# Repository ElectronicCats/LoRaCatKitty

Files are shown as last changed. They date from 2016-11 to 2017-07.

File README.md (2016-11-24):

# LoRa Cat: Kitty

Electronic Cats invests time and resources providing this open source design, please support Electronic Cats and open-source hardware by purchasing products from Electronic Cats!

Designed by Electronic Cats.

Firmware released under an GNU AGPL v3.0 license. See the LICENSE file for more information.

Hardware released under an CERN Open Hardware Licence v1.2. See the LICENSE_HARDWARE file for more information.

Electronic Cats is a registered trademark, please do not use if you sell these PCBs.

23 Nov 2016

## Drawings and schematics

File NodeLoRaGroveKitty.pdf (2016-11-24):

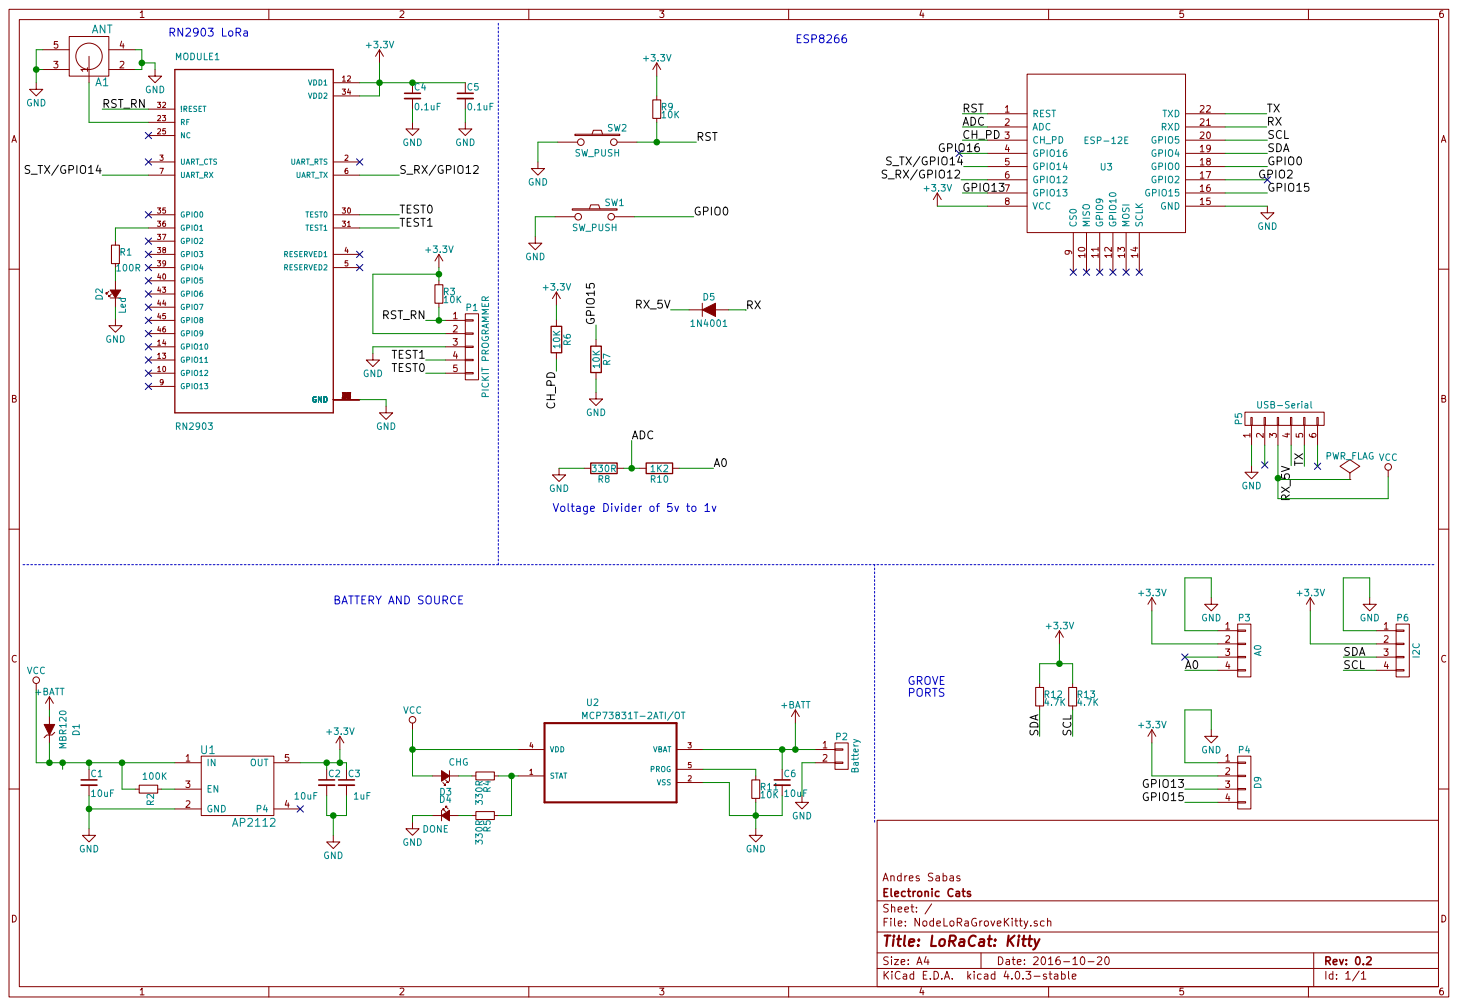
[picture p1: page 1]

9 MISO 10 GPIO5 20 GPIO9 11 RXD 21 GPIO10 12 TXD 22 MOSI 13 SCLK 14 GND 15 GPIO15 16 GPIO2 17 GPIO0 18 GPIO4 19 U3 ESP-12E TXRX

Voltage Divider of 5v to 1v

File: NodeLoRaGroveKitty.sch Sheet: / Electronic Cats Andres Sabas

Id: 1/1 Title: LoRaCat: Kitty

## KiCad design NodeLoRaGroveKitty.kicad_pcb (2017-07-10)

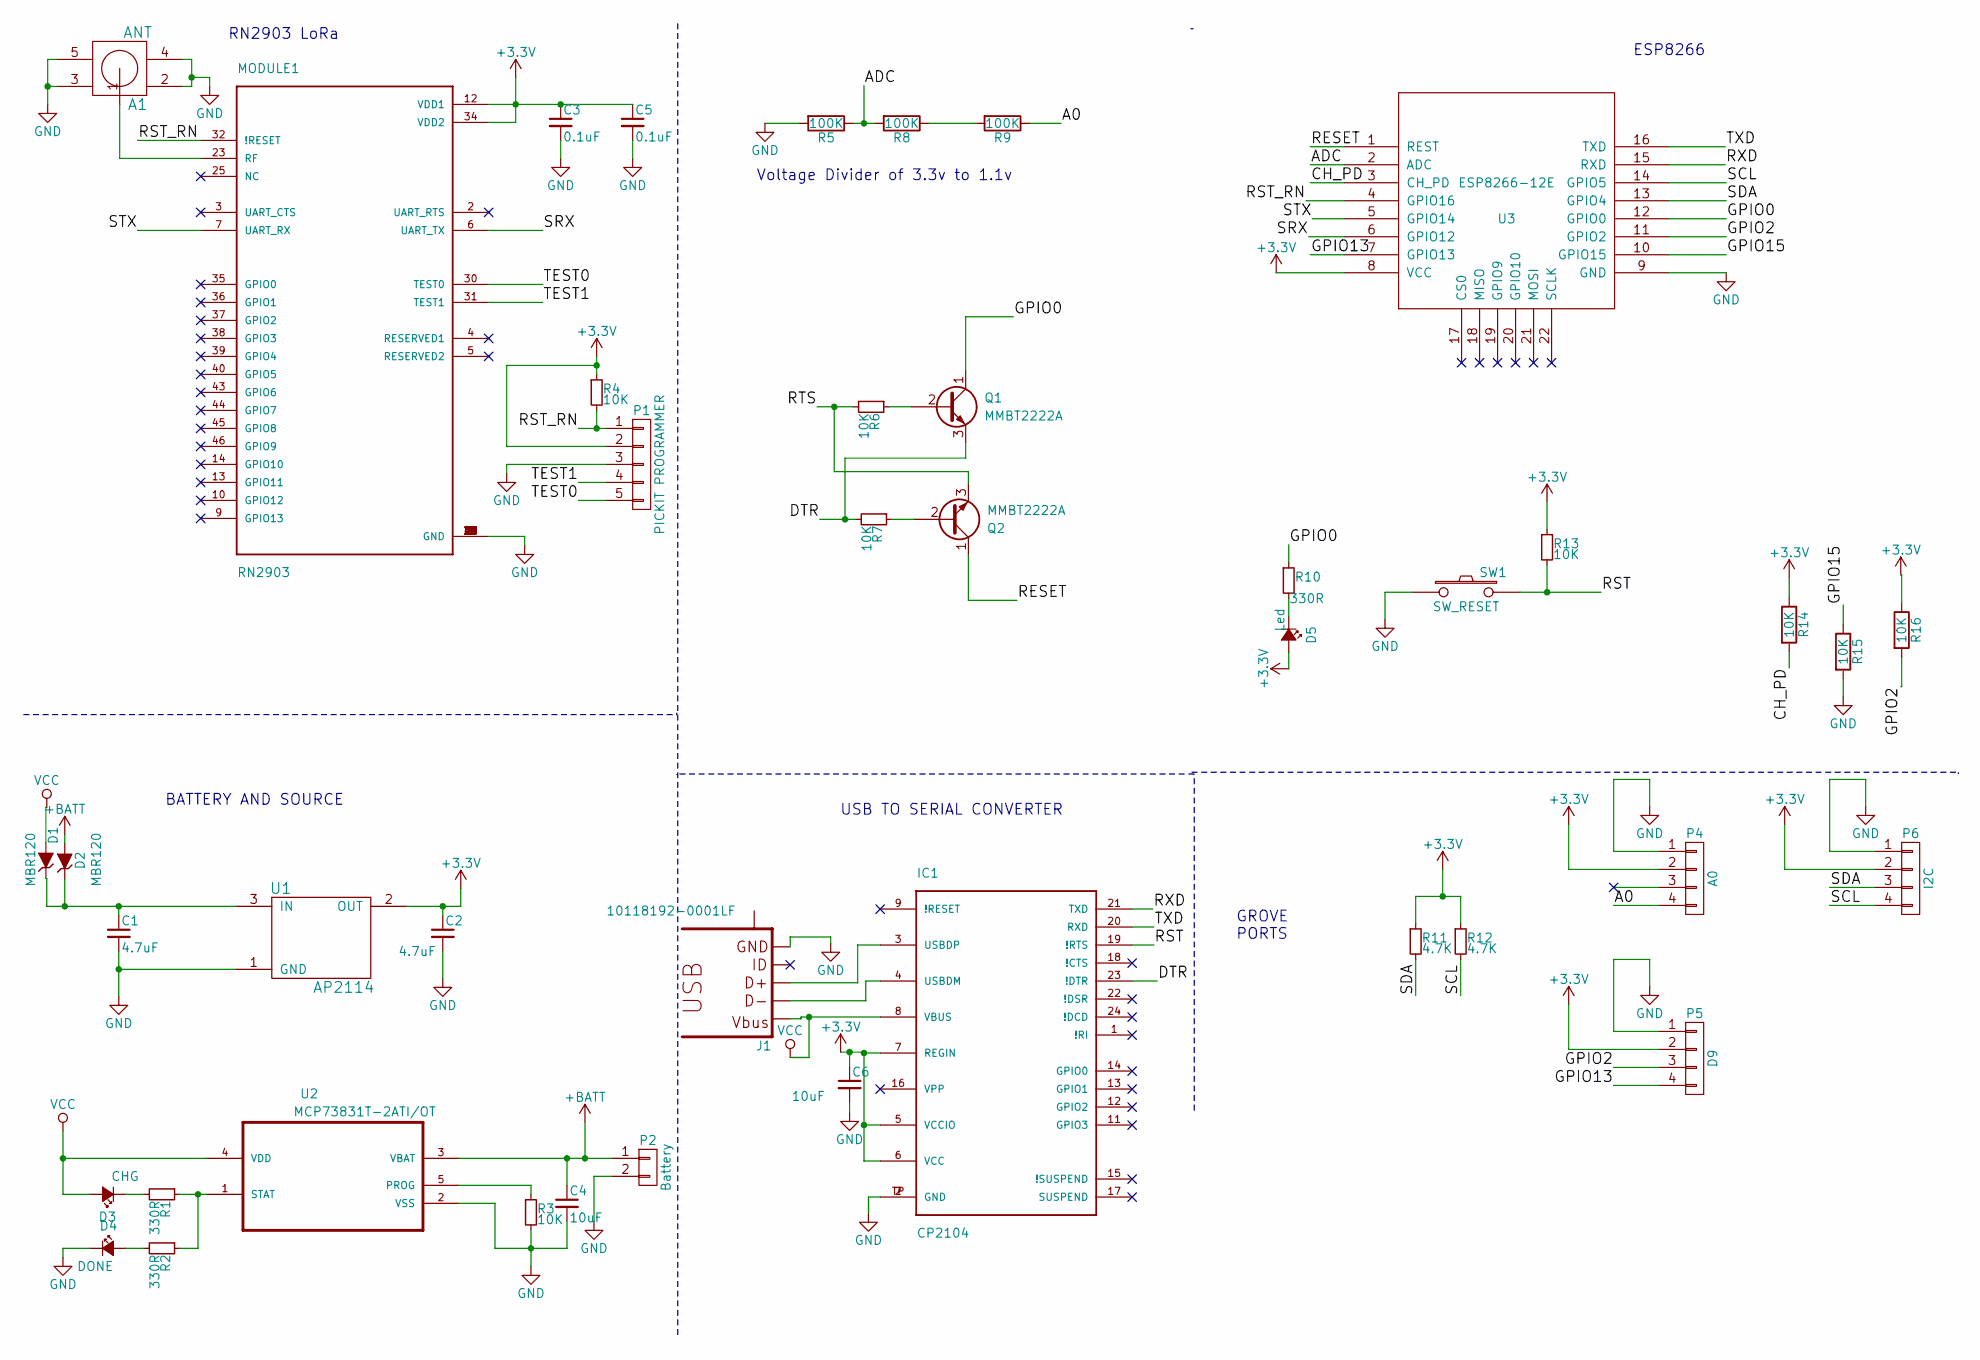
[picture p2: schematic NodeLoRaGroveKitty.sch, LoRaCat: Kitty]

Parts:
A1: ANT; SMA_Conn_Ant
C1, C2: 4.7uF; C_0805_HandSoldering
C3, C5: 0.1uF; C_0805_HandSoldering
C4, C6: 10uF; C_0805_HandSoldering
D1, D2: MBR120; D_SOD-123
D3: CHG; LED_0805
D4: DONE; LED_0805
D5: Led; LED_0805
IC1: CP2104; QFN-24_4x4mm_Pitch0.5mm_NoMask
J1: 10118192-0001LF
MODULE1: RN2903; RN2483
P1: PICKIT PROGRAMMER; Pin_Header_Straight_1x05_Pitch2.54mm
P2: Battery; panelmate_smd_2
P4: A0; JST_PH_S4B-PH-SM4-TB_04x2.00mm_Angled
P5: D9; JST_PH_S4B-PH-SM4-TB_04x2.00mm_Angled
P6: I2C; JST_PH_S4B-PH-SM4-TB_04x2.00mm_Angled
Q1, Q2: MMBT2222A; SOT-23
R1, R2, R10: 330R; R_0805_HandSoldering
R3, R4, R6, R7, R13, R14, R15, R16: 10K; R_0805_HandSoldering
R5, R8, R9: 100K; R_0805_HandSoldering
R11, R12: 4.7K; R_0805_HandSoldering
SW1: SW_RESET; SW_SPST_B3U-1000P
U1: AP2114; SOT-223-3Lead_TabPin2
U2: MCP73831T-2ATI/OT; SOT-23-5
U3: ESP8266-12E; ESP-12E

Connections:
+3V3: C2.1, C3.1, C5.1, C6.1, D5.2 (A), IC1.5 (VCCIO), IC1.6 (VCC), IC1.7 (REGIN), MODULE1.12 (VDD1), MODULE1.34 (VDD2), P1.2, P4.2, P5.2, P6.2, R4.1, R11.1, R12.1, R13.1, R14.1, R16.1, U1.2 (OUT), U3.8 (VCC)
+BATT: C4.1, D2.2 (A), P2.1, U2.3 (VBAT)
/A0: P4.4, R9.1
/ADC: R5.1, R8.2, U3.2 (ADC)
/CH_PD: R14.2, U3.3 (CH_PD)
/DTR: IC1.23 (!DTR), Q1.3 (E), R7.2
/GPIO0: Q1.1 (C), R10.1, U3.12 (GPIO0)
/GPIO2: P5.3, R16.2, U3.11 (GPIO2)
/GPIO13: P5.4, U3.7 (GPIO13)
/GPIO15: R15.1, U3.10 (GPIO15)
/RESET: Q2.1 (C), U3.1 (REST)
/RST: IC1.19 (!RTS), R13.2, SW1.2; also elsewhere on the board
/RST_RN: MODULE1.32 (!RESET), P1.1, R4.2, U3.4 (GPIO16)
/RTS: Q2.3 (E), R6.2
/RXD: IC1.21 (TXD), U3.15 (RXD)
/SCL: P6.4, R12.2, U3.14 (GPIO5)
/SDA: P6.3, R11.2, U3.13 (GPIO4)
/SRX: MODULE1.6 (UART_TX), U3.6 (GPIO12)
/STX: MODULE1.7 (UART_RX), U3.5 (GPIO14)
/TEST0: MODULE1.30 (TEST0), P1.5
/TEST1: MODULE1.31 (TEST1), P1.4
/TXD: IC1.20 (RXD), U3.16 (TXD)
GND: A1.2, A1.3, A1.4, A1.5, C1.2, C2.2, C3.2, C4.2, C5.2, C6.2, D4.1 (K), IC1.2 (GND), IC1.TP (GND), J1.5 (GND), MODULE1.1 (GND), MODULE1.8 (GND), MODULE1.11 (GND), MODULE1.20 (GND), MODULE1.21 (GND), MODULE1.22 (GND), MODULE1.24 (GND), MODULE1.26 (GND), MODULE1.27 (GND), MODULE1.28 (GND), MODULE1.33 (GND), MODULE1.41 (GND), MODULE1.47 (GND), P1.3, P2.2, P4.1, P5.1, P6.1, R3.2, R5.2, R15.2, SW1.1, U1.1 (GND), U2.2 (VSS), U3.9 (GND); also elsewhere on the board
unnamed: A1.1, MODULE1.23 (RF)
unnamed: C1.1, D1.1 (K), D2.1 (K), U1.3 (IN)
unnamed: D3.1 (K), R1.2
unnamed: D4.2 (A), R2.2
unnamed: D5.1 (K), R10.2
unnamed: IC1.3 (USBDP), J1.3 (D+)
unnamed: IC1.4 (USBDM), J1.2 (D-)
unnamed: J1.M1 (S), J1.M2 (S), J1.S1 (S), J1.S2 (S), J1.S3 (S), J1.S4 (S)
unnamed: Q1.2 (B), R6.1
unnamed: Q2.2 (B), R7.1
unnamed: R1.1, R2.1, U2.1 (STAT)
unnamed: R3.1, U2.5 (PROG)
unnamed: R8.1, R9.2
VCC: D1.2 (A), D3.2 (A), IC1.8 (VBUS), J1.1 (VBUS), U2.4 (VDD)

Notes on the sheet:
RN2903 LoRa
ESP8266
GROVE PORTS
BATTERY AND SOURCE
Voltage Divider of 3.3v to 1.1v
USB TO SERIAL CONVERTER

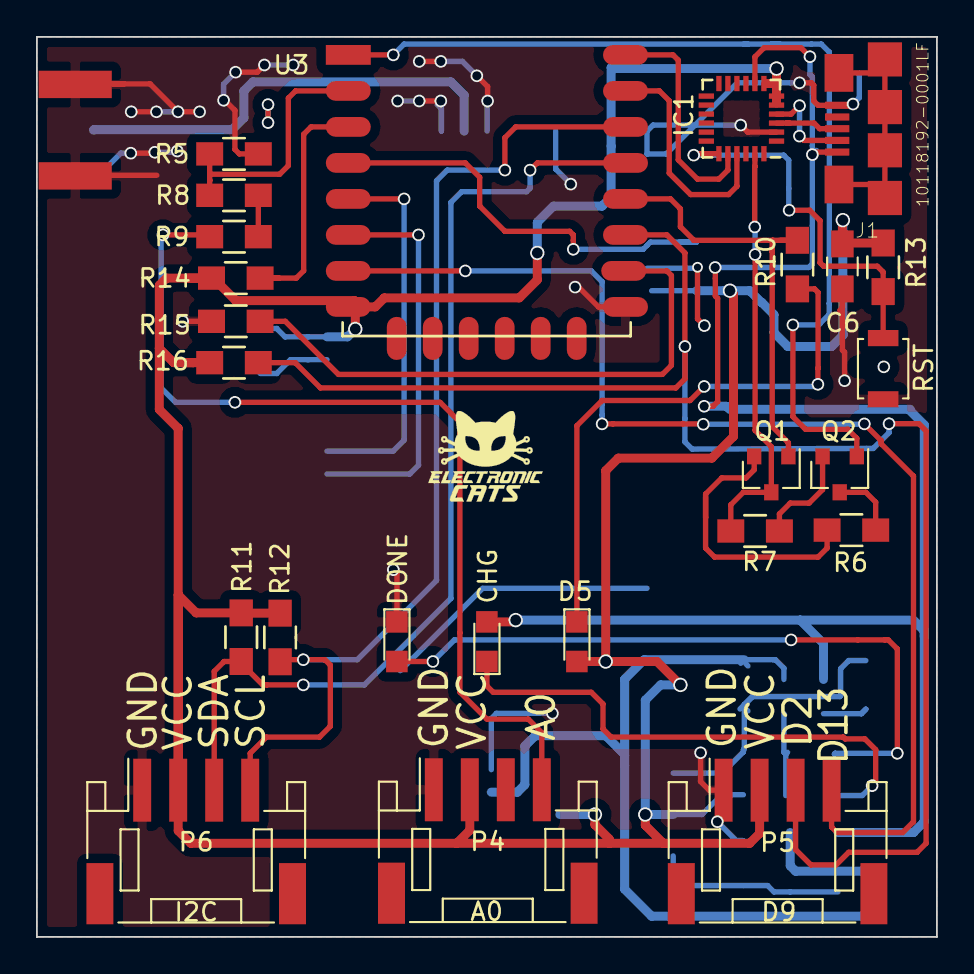
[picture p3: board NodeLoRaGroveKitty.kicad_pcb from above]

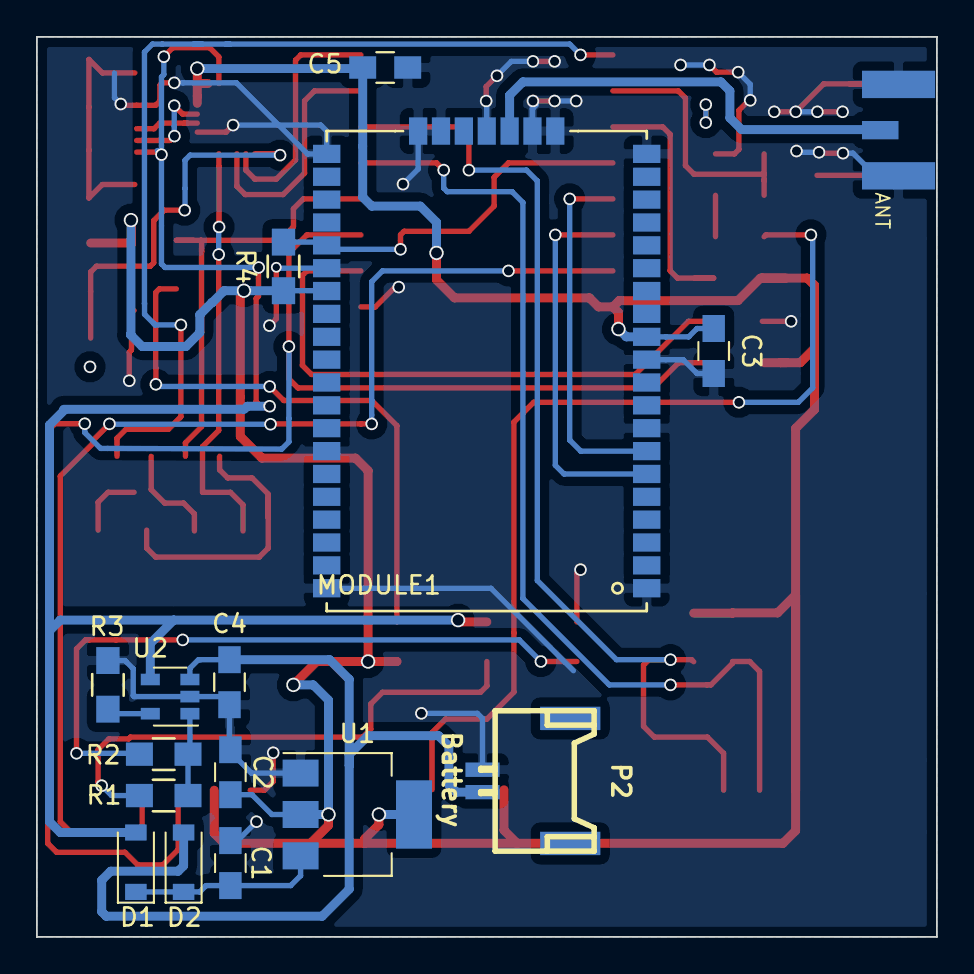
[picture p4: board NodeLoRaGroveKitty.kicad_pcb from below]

Board: 2 copper layers, 50.0 x 50.0 mm, 41 parts (16 on the bottom side), 35 nets.

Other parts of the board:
RST: SW_RESET; SW_SPST_B3U-1000P

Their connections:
/RST: RST.2; also elsewhere on the board
GND: RST.1; also elsewhere on the board

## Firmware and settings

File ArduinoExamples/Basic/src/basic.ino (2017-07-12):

/*
 * Author: Andres Sabas @ Electronic Cats
 * Date: 2017-01-27
 *
 * Example for LoRa Kitty with OTA and ABP or OTAA LORAWAM
 * Transmit a one byte packet via LoRaWAN. This happens as fast as possible, while still keeping to
 * the 1% duty cycle rules enforced by the RN2xx3's built in LoRaWAN stack. Even though this is
 * allowed by the radio regulations of the 868MHz and 915Mhz band, the fair use policy of LoRaWAN may prohibit this.
 *
 * CHECK THE RULES BEFORE USING THIS PROGRAM!
 *
 * CHANGE ADDRESS!
 * Change the device address, network (session) key, and app (session) key to the values
 * that are registered via the LoRa dashboard.
 * The appropriate line is "myLora.initABP(XXX);" or "myLora.initOTAA(XXX);"
 * When using ABP, it is advised to enable "relax frame count".
 *
 * Connect the RN2xx3 as follows:
 * RN2xx3 -- ESP8266
 * Uart TX -- GPIO12
 * Uart RX -- GPIO14
 * Reset -- GPIO16
 * Vcc -- 3.3V
 * Gnd -- Gnd
 *
 */


#include <rn2xx3.h>
#include <SoftwareSerial.h>
#include <ESP8266WiFi.h>
#include <ESP8266mDNS.h>
#include <WiFiUdp.h>
#include <ArduinoOTA.h>
#include <CayenneLPP.h>

//Use Low Power Payload https://mydevices.com/cayenne/docs/lora/#lora-cayenne-low-power-payload
CayenneLPP lpp(51);

const char* ssid = "TIH-Alpha2.4";
const char* password = "";

#define RESET 16
SoftwareSerial mySerial(12, 14); // RX, TX !! labels on relay board is swapped !!

//create an instance of the rn2xx3 library,
//giving the software UART as stream to use,
//and using LoRa WAN
rn2xx3 myLora(mySerial);

// the setup routine runs once when you press reset:
void setup() {
  // LED pin is GPIO2 which is the ESP8266's built in LED
  pinMode(2, INPUT);

  // Open serial communications and wait for port to open:
  Serial.begin(115200);
  mySerial.begin(57600);

  delay(10); //wait for the arduino ide's serial console to open

  Serial.println("Setup WiFi Connection");

  Serial.println();
  Serial.println();
  Serial.print("Connecting to ");
  Serial.println(ssid);

  WiFi.mode(WIFI_STA);
  WiFi.begin(ssid, password);

  while (WiFi.waitForConnectResult() != WL_CONNECTED) {
    Serial.println("Connection Failed! No WiFi!...");
    //delay(5000);
    //ESP.restart();
    break;
}

/*
while (WiFi.status() != WL_CONNECTED) {
  delay(500);
  Serial.print(".");
}*/

if(WiFi.waitForConnectResult() == WL_CONNECTED) {


    // Port defaults to 8266
    // ArduinoOTA.setPort(8266);

    // Hostname defaults to esp8266-[ChipID]
    // ArduinoOTA.setHostname("myesp8266");

    // No authentication by default
    // ArduinoOTA.setPassword("admin");

    // Password can be set with it's md5 value as well
    // MD5(admin) = 21232f297a57a5a743894a0e4a801fc3
    // ArduinoOTA.setPasswordHash("21232f297a57a5a743894a0e4a801fc3");
/*
    ArduinoOTA.onStart([]() {
      String type;
      if (ArduinoOTA.getCommand() == U_FLASH)
        type = "sketch";
      else // U_SPIFFS
        type = "filesystem";

      // NOTE: if updating SPIFFS this would be the place to unmount SPIFFS using SPIFFS.end()
      Serial.println("Start updating " + type);

    });
    */
    ArduinoOTA.onEnd([]() {
      Serial.println("\nEnd");
    });
    ArduinoOTA.onProgress([](unsigned int progress, unsigned int total) {
      Serial.printf("Progress: %u%%\r", (progress / (total / 100)));
    });
    ArduinoOTA.onError([](ota_error_t error) {
      Serial.printf("Error[%u]: ", error);
      if (error == OTA_AUTH_ERROR) Serial.println("Auth Failed");
      else if (error == OTA_BEGIN_ERROR) Serial.println("Begin Failed");
      else if (error == OTA_CONNECT_ERROR) Serial.println("Connect Failed");
      else if (error == OTA_RECEIVE_ERROR) Serial.println("Receive Failed");
      else if (error == OTA_END_ERROR) Serial.println("End Failed");
    });

    ArduinoOTA.begin();


    Serial.println("Ready");
    Serial.print("IP address: ");
    Serial.println(WiFi.localIP());
}
  //initialize radio LoRa
  initialize_radio();
}

void initialize_radio()
{
  //reset RN2xx3
  pinMode(RESET, OUTPUT);
  digitalWrite(RESET, LOW);
  delay(100);
  digitalWrite(RESET, HIGH);

  delay(100); //wait for the RN2xx3's startup message
  mySerial.flush();

  //check communication with radio
  String hweui = myLora.hweui();
  while(hweui.length() != 16)
  {
    Serial.println("Communication with RN2xx3 unsuccesful. Power cycle the board.");
    Serial.println(hweui);
    delay(10000);
    hweui = myLora.hweui();
  }

  //print out the HWEUI so that we can register it via ttnctl
  Serial.println("When using OTAA, register this DevEUI: ");
  Serial.println(hweui);
  Serial.println("RN2xx3 firmware version:");
  Serial.println(myLora.sysver());

  //configure your keys and join the network
  Serial.println("Trying to join TTN");
  bool join_result = false;

  //ABP: initABP(String addr, String AppSKey, String NwkSKey);
  //join_result = myLora.initABP("26021B7C", "3D016DF9E60F6270890FDC2B753C0E99", "EA40E937CF5592742ECA30DEBC1954E5");

  //OTAA: initOTAA(String AppEUI, String AppKey);
  join_result = myLora.initOTAA("70B3D57EF00062AD", "150C667A235B003361457751594DCAFB");

  while(!join_result)
  {
    Serial.println("Unable to join. Are your keys correct, and do you have TTN coverage?");
    delay(30000); //delay a 30 seg before retry
    join_result = myLora.init();
  }
  Serial.println("Successfully joined TTN");

}

// the loop routine runs over and over again forever:
void loop() {
    ArduinoOTA.handle();
    //Reset buffer of lpp
    lpp.reset();

    //Read button
    read_button();

    //Read light
    read_light();

    Serial.println("Sending Data");
    myLora.txBytes(lpp.getBuffer(), lpp.getSize());

    delay(30000); // delay 30 seg for TTN
}

void read_light(){
  int light = analogRead(0);
  Serial.println(light);
  lpp.addAnalogInput(1, light);
}

void read_button(){
  if(digitalRead(2)==1){
    Serial.println("Button press!");
    lpp.addDigitalInput(2, 1);
  }
  else
  {
    Serial.println("Button NO press");
    lpp.addDigitalInput(2, 0);
  }


}

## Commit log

2016-11-24 Added Squematic
    [NodeLoRaGroveKitty.kicad_pcb, NodeLoRaGroveKitty.sch]
2016-12-06 Fix ADC pin
    [NodeLoRaGroveKitty.sch]
2016-12-13 Added Library footprint
2016-12-13 Update Grove to 5v
    [NodeLoRaGroveKitty.sch]
2016-12-13 Validate footprints
    [NodeLoRaGroveKitty.kicad_pcb]
2016-12-14 Correct to 3.3v, and R10
    [NodeLoRaGroveKitty.sch]
2016-12-14 Add first PCB design
    [NodeLoRaGroveKitty.kicad_pcb]
2016-12-15 Fix pines S_TX and S_RX
    [NodeLoRaGroveKitty.sch]
2016-12-15 Added Logos
    [NodeLoRaGroveKitty.kicad_pcb]
2016-12-15 Added labels pinout
    [NodeLoRaGroveKitty.kicad_pcb]
2016-12-16 Change GPIO2
    [NodeLoRaGroveKitty.sch]
2017-01-02 Add pin reset for RN
    GPIO16
    [NodeLoRaGroveKitty.sch]
2017-01-02 Fix non-copper area
    [NodeLoRaGroveKitty.kicad_pcb]
2017-01-02 Fix label's
    [NodeLoRaGroveKitty.kicad_pcb]
2017-01-03 Add resistence and pin reset
    [NodeLoRaGroveKitty.kicad_pcb]
2017-01-03 Add res and rst pin PCB and Label's
    [NodeLoRaGroveKitty.kicad_pcb]
2017-01-03 Update logos
    [NodeLoRaGroveKitty.kicad_pcb]
2017-01-04 Fix bug footprint
    [NodeLoRaGroveKitty.kicad_pcb, NodeLoRaGroveKitty.sch]
2017-01-04 Fix re-bug
    [NodeLoRaGroveKitty.kicad_pcb]
2017-01-10 Update BOM
    [NodeLoRaGroveKitty.kicad_pcb, NodeLoRaGroveKitty.sch]
2017-01-28 Change to AP2114
    [NodeLoRaGroveKitty.sch]
2017-02-01 Add mbr120
    [NodeLoRaGroveKitty.sch]
2017-02-01 Change Led to GPIO0
    [NodeLoRaGroveKitty.sch]
2017-02-08 Fix Rename pin D15 to D2
    [NodeLoRaGroveKitty.kicad_pcb]
2017-02-11 Change D2 for D13
    [NodeLoRaGroveKitty.sch]
2017-02-16 Added autoreset and USB_Serial
    [NodeLoRaGroveKitty.sch]
2017-02-16 Version 0.5
    [NodeLoRaGroveKitty.sch]
2017-02-19 Update AP2114, fix bugs JST
    [NodeLoRaGroveKitty.kicad_pcb, NodeLoRaGroveKitty.sch]
2017-02-19 New design PCB
    [NodeLoRaGroveKitty.kicad_pcb, NodeLoRaGroveKitty.sch]
2017-02-21 PCB 1.0v
    [NodeLoRaGroveKitty.kicad_pcb, NodeLoRaGroveKitty.sch]
2017-02-21 Update Labels
    [NodeLoRaGroveKitty.kicad_pcb]
2017-02-21 Update inverter label
    [NodeLoRaGroveKitty.kicad_pcb]
2017-04-12 Change USB with libraries
    [NodeLoRaGroveKitty.kicad_pcb, NodeLoRaGroveKitty.sch]
2017-04-14 Add #maf to battery conector
    [NodeLoRaGroveKitty.sch]
2017-05-03 Add new RN and fix ways
    [NodeLoRaGroveKitty.kicad_pcb, NodeLoRaGroveKitty.sch]
2017-05-03 Fix gnd
    [NodeLoRaGroveKitty.kicad_pcb]
2017-07-10 fix connects
    [NodeLoRaGroveKitty.kicad_pcb]
2017-07-11 Added LLP, read button and light sensor
2017-07-12 Rename folder KicadLibrary
